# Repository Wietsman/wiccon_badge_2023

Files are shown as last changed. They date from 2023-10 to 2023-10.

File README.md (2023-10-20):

# Wiccon Badge 2023

# What is this repo: 
  This repo contains the source + firmware + PCB design for the WICCON 2023 Badge (https://wiccon.nl/) (not the SAO)

  Badge front:
Frontside  

  Badge back:
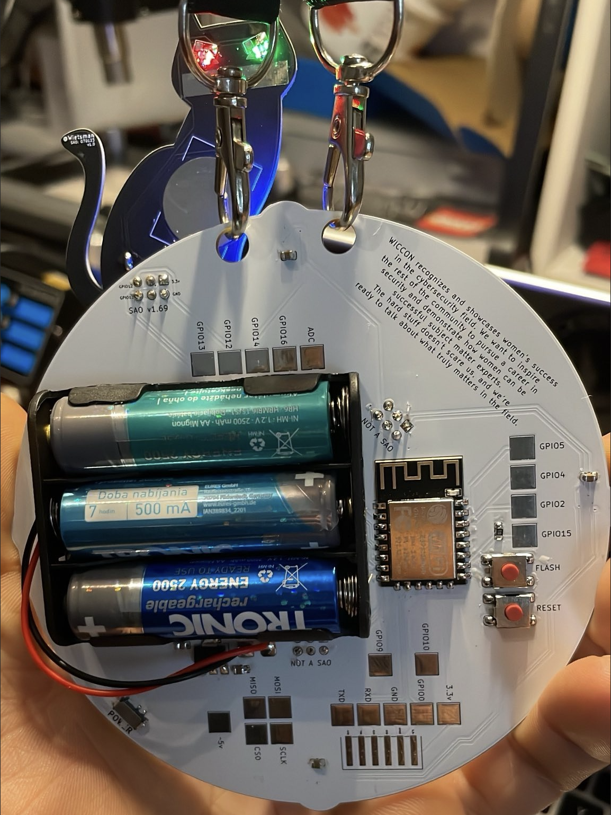
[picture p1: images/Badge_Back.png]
Backside
    

  The Folder PCB contains the main badge and the addon, created with KiCad.
  # Main badge
  ## Frontside
  * 4 WS2812B on the front. (made a mistake they are adressed counter clockwise)
  * 1 MODE button on the front to switch LED effects
  * 2 6 pin female connecter to attach the addon board (Cat and moon)
  * 1 SAO v1.69 (Shitty Addon) (https://hackaday.com/2019/03/20/introducing-the-shitty-add-on-v1-69bis-standard/)
  * |  PIN  |      Description      |
    |-------|-----------------------|
    | 3.3v  | Positive power supply |
    | GND   | Ground                |
    | SCL   | Not connected (sorry) |
    | SDA   | Not connected (sorry) |        
    | GPI12 | General-purpose pin   |
    | GPI13 | General-purpose pin   |    
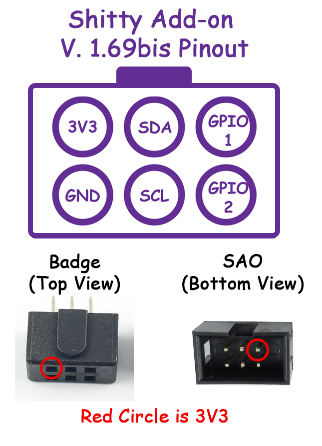
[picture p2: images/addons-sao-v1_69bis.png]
SAO v1.69


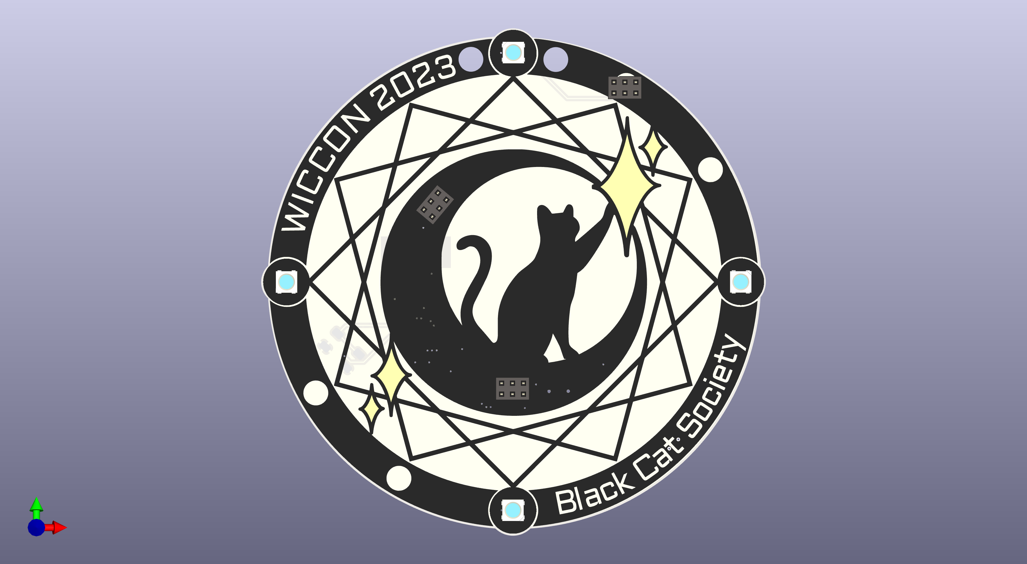
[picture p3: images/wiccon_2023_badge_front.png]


## Backside
* ESP8622
* Powerswitch
* Reset button
* Flash button
* Batterybox
* stepdown converter (3.6-4.5v) to 3.3v
* couple of capacitor for WS2812B and stepdown converter
* 1 resistor
* lots of test pads so you can reuse the badge for other projects

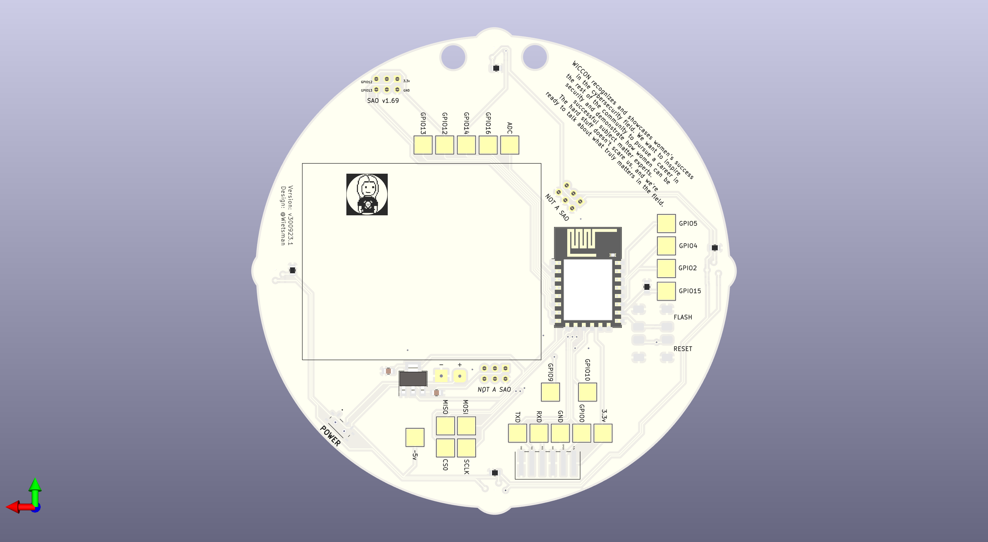
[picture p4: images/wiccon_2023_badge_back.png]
back3d


## Schematic
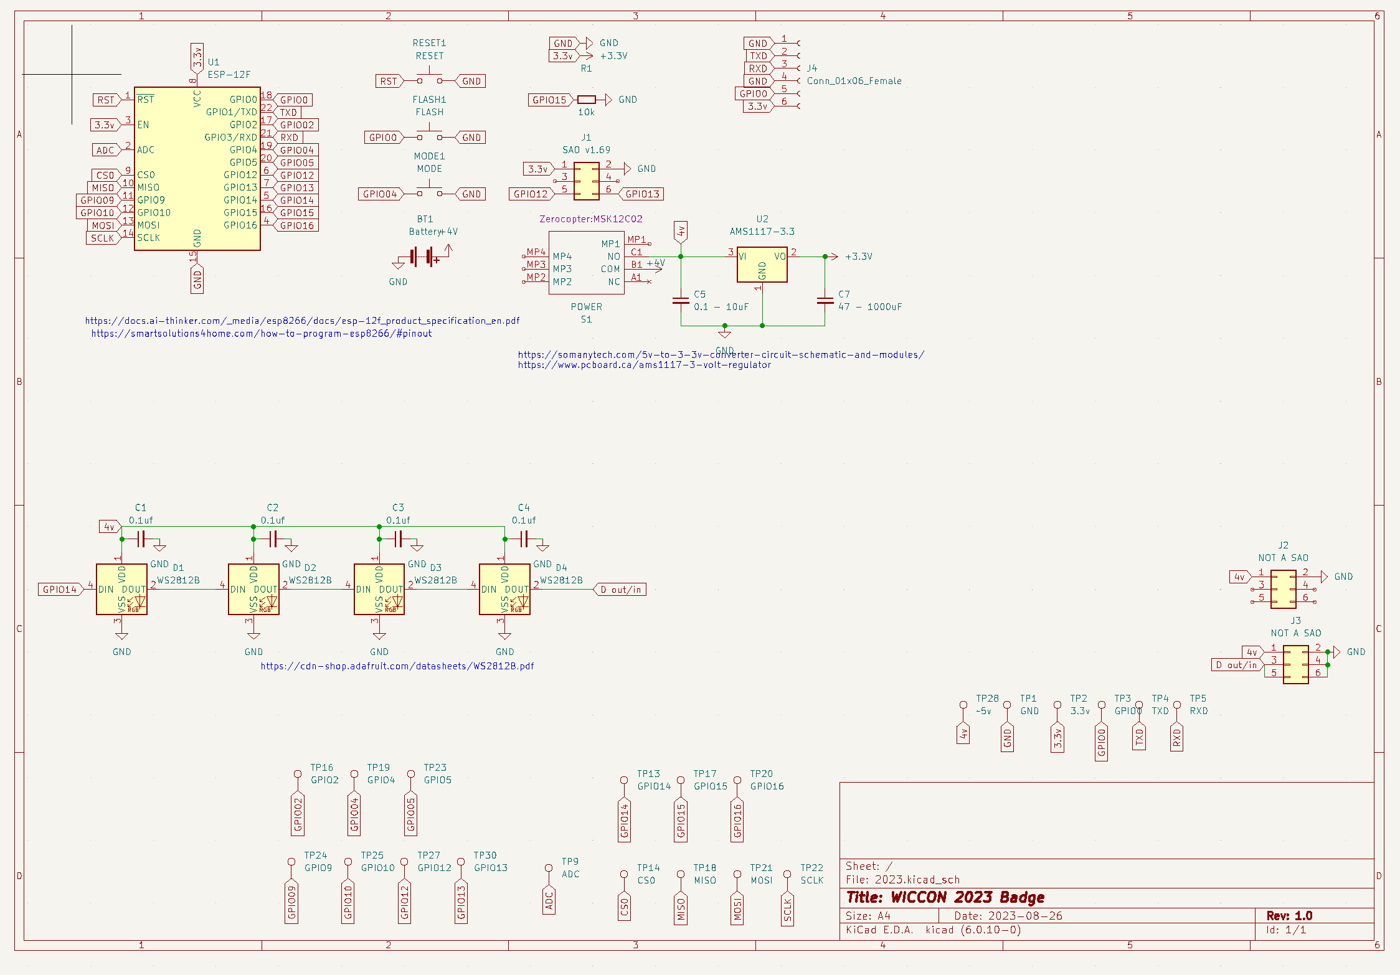
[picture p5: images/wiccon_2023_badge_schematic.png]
Schematic


## Usage
The badge has been designed to be reused for your project. The test pads can be used to solder anything to it and you can flash the ESP. 

You can use all the pads/pins except for (because i orderd the wrong ESP.....):
* MISO
* MOSI
* GPIO09
* GPIO10
* SCLK
* CSO

The following pins need are "special":
* GPIO00 pull to ground on boot to flash the ESP (or press flash button)
* GPIO15 is pulled to ground through a 10k resistor otherwise the ESP wont boot.

Flashing your own firmware, connect UART to tx/rx gnd power the device by battery or external 3.3v power. Hold the flash button, then press reset, release the flash button. Now you can flash your own firmware with esptool.py, arduino ide or what ever you want.

# Addon board
There are 2 addon boards for WICCON 2023, for guests (black cat and moon) and orga (purple moon, silver cat)
## Guestboard
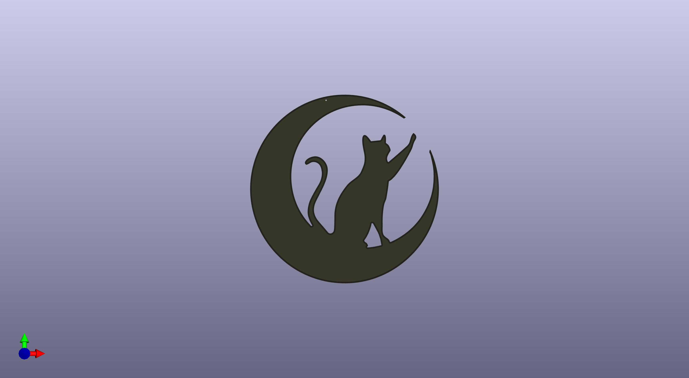
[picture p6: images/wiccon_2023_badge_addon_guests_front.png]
guest cat

## Orgaboard
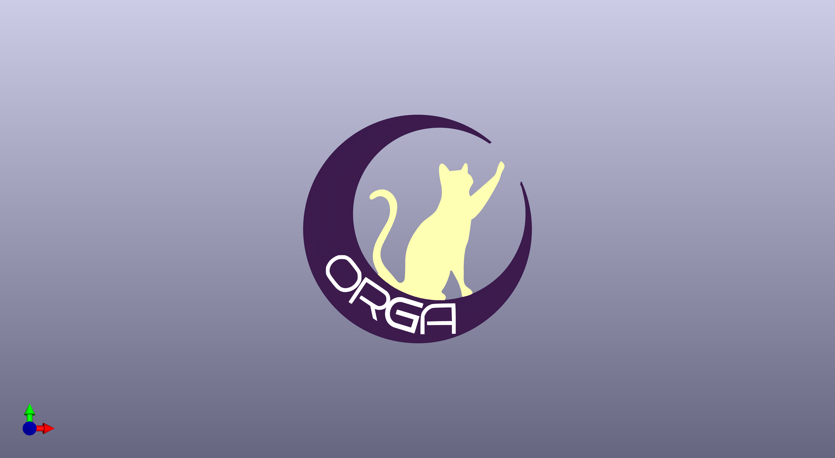
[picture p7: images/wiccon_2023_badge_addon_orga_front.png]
orga cat

## Schematic
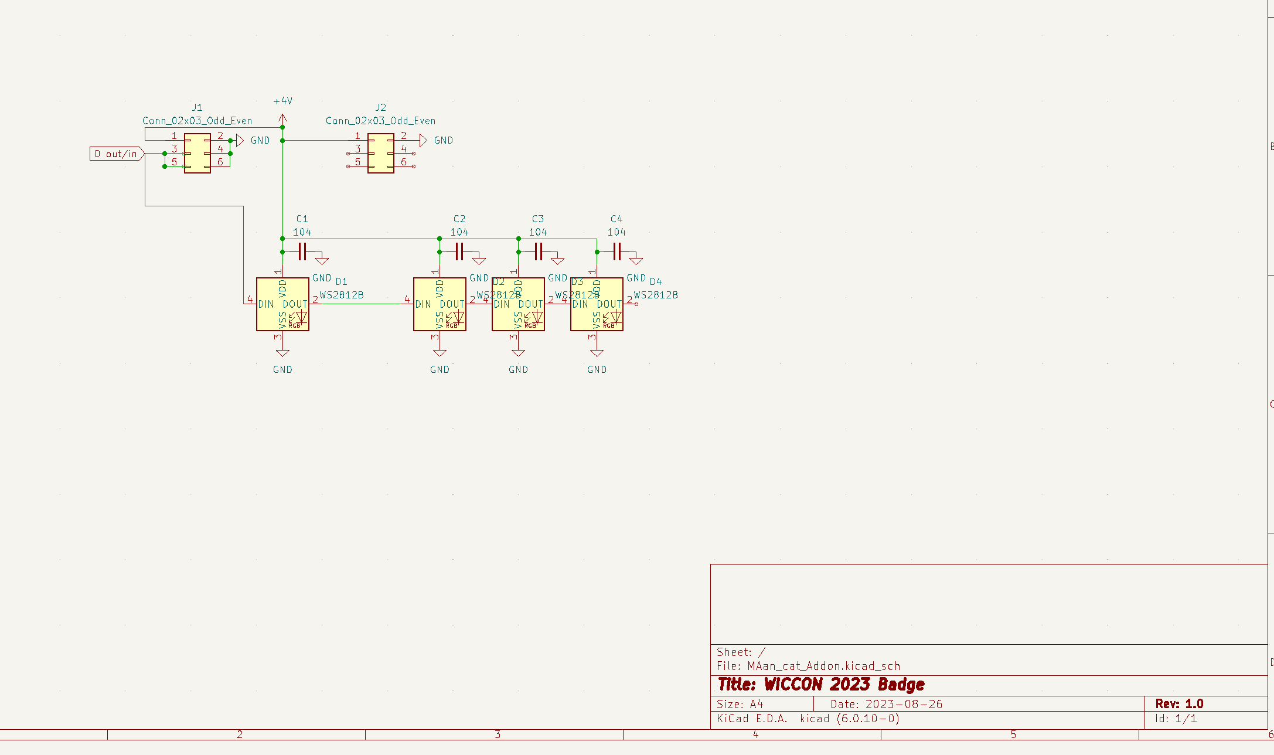
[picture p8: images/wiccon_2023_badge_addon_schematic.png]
schematic


## Backside
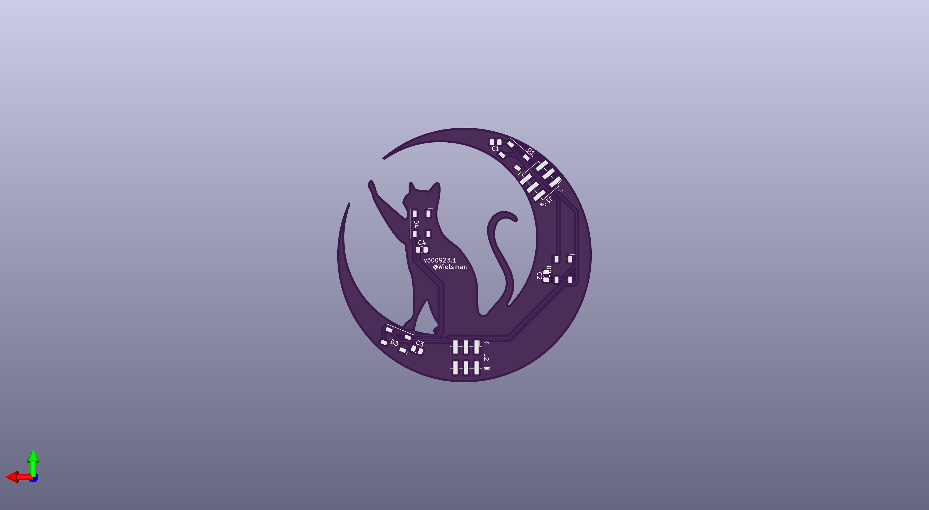
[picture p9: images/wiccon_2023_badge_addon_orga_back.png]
backside


# Questions, remarks or whatever!

If you have any questions please drop me a message: 
* twitter: [twitter](https://twitter.com/wietsman)
* Website: [WBSEC.nl](https://www.wbsec.nl)

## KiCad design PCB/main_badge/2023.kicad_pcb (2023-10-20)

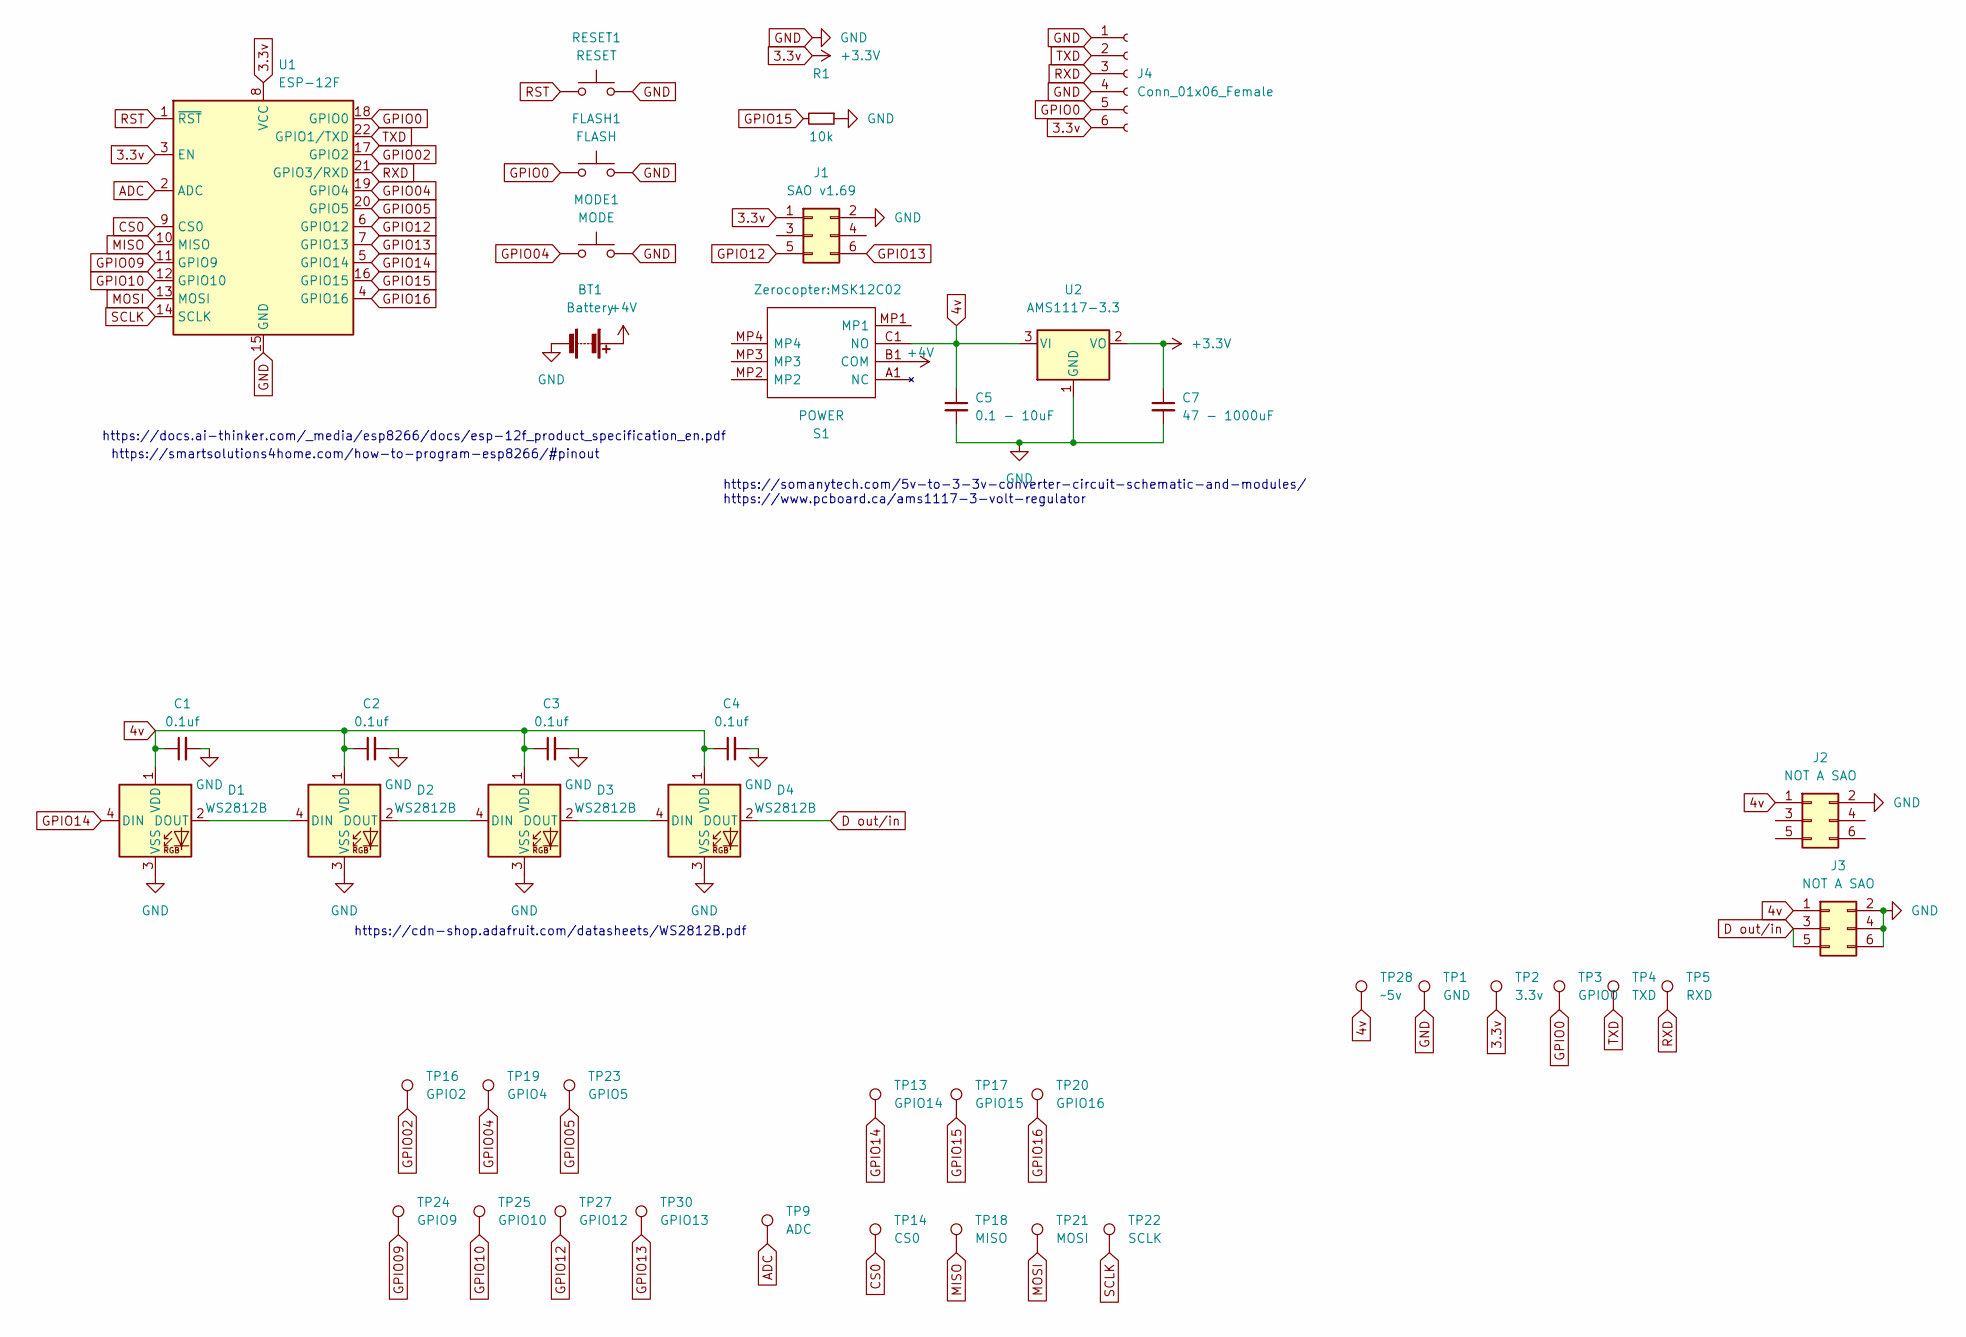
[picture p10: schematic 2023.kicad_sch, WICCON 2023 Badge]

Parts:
BT1: Battery; Battery_holder_3AA
C1, C2, C3, C4: 0.1uf; R_0805_2012Metric
C5: 0.1 - 10uF; C_0805_2012Metric_Pad1.18x1.45mm_HandSolder
C7: 47 - 1000uF; C_0805_2012Metric_Pad1.18x1.45mm_HandSolder
D1, D2, D3, D4: WS2812B; LED_WS2812B_PLCC4_5.0x5.0mm_P3.2mm
FLASH1: FLASH; sw_tactile_4x4
J1: SAO v1.69; PinSocket_2x03_P2.54mm_Vertical
J2, J3: NOT A SAO; PinSocket_2x03_P2.54mm_Vertical
J4: Conn_01x06_Female; Harting_har-flexicon_14110413010xxx_1x04-MP_P2.54mm_Horizon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
MODE1: MODE; sw_tactile_4x4
R1: 10k; R_0805_2012Metric_Pad1.20x1.40mm_HandSolder
RESET1: RESET; sw_tactile_4x4
S1: POWER; MSK12C02; Manufacturer_Part_Number MSK12C02
TP1: GND; TestPoint_Pad_4.0x4.0mm
TP2: 3.3v; TestPoint_Pad_4.0x4.0mm
TP3: GPIO0; TestPoint_Pad_4.0x4.0mm
TP4: TXD; TestPoint_Pad_4.0x4.0mm
TP5: RXD; TestPoint_Pad_4.0x4.0mm
TP9: ADC; TestPoint_Pad_4.0x4.0mm
TP13: GPIO14; TestPoint_Pad_4.0x4.0mm
TP14: CS0; TestPoint_Pad_4.0x4.0mm
TP16: GPIO2; TestPoint_Pad_4.0x4.0mm
TP17: GPIO15; TestPoint_Pad_4.0x4.0mm
TP18: MISO; TestPoint_Pad_4.0x4.0mm
TP19: GPIO4; TestPoint_Pad_4.0x4.0mm
TP20: GPIO16; TestPoint_Pad_4.0x4.0mm
TP21: MOSI; TestPoint_Pad_4.0x4.0mm
TP22: SCLK; TestPoint_Pad_4.0x4.0mm
TP23: GPIO5; TestPoint_Pad_4.0x4.0mm
TP24: GPIO9; TestPoint_Pad_4.0x4.0mm
TP25: GPIO10; TestPoint_Pad_4.0x4.0mm
TP27: GPIO12; TestPoint_Pad_4.0x4.0mm
TP28: ~5v; TestPoint_Pad_4.0x4.0mm
TP30: GPIO13; TestPoint_Pad_4.0x4.0mm
U1: ESP-12F; ESP-12E
U2: AMS1117-3.3; SOT-223-3_TabPin2

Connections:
3.3v: C7.1, J1.1, J4.6, TP2.1, U1.3 (EN), U1.8 (VCC), U2.2 (VO)
4v: C1.1, C2.1, C3.1, C4.1, C5.1, D1.1 (VDD), D2.1 (VDD), D3.1 (VDD), D4.1 (VDD), J2.1, J3.1, S1.C1 (NO), TP28.1, U2.3 (VI)
+4V: BT1.1 (+), S1.B1 (COM)
ADC: TP9.1, U1.2 (ADC)
CS0: TP14.1, U1.9 (CS0)
D out/in: D4.2 (DOUT), J3.3, J3.5
GND: BT1.2 (-), C1.2, C2.2, C3.2, C4.2, C5.2, C7.2, D1.3 (VSS), D2.3 (VSS), D3.3 (VSS), D4.3 (VSS), FLASH1.2, J1.2, J2.2, J3.2, J3.4, J3.6, J4.1, J4.4, MODE1.2, R1.1, RESET1.2, TP1.1, U1.15 (GND), U2.1 (GND)
GPIO0: FLASH1.1, J4.5, TP3.1, U1.18 (GPIO0)
GPIO02: TP16.1, U1.17 (GPIO2)
GPIO04: MODE1.1, TP19.1, U1.19 (GPIO4)
GPIO05: TP23.1, U1.20 (GPIO5)
GPIO09: TP24.1, U1.11 (GPIO9)
GPIO10: TP25.1, U1.12 (GPIO10)
GPIO12: J1.5, TP27.1, U1.6 (GPIO12)
GPIO13: J1.6, TP30.1, U1.7 (GPIO13)
GPIO14: D1.4 (DIN), TP13.1, U1.5 (GPIO14)
GPIO15: R1.2, TP17.1, U1.16 (GPIO15)
GPIO16: TP20.1, U1.4 (GPIO16)
MISO: TP18.1, U1.10 (MISO)
MOSI: TP21.1, U1.13 (MOSI)
unnamed: D1.2 (DOUT), D2.4 (DIN)
unnamed: D2.2 (DOUT), D3.4 (DIN)
unnamed: D3.2 (DOUT), D4.4 (DIN)
RST: RESET1.1, U1.1 (~RST)
RXD: J4.3, TP5.1, U1.21 (GPIO3/RXD)
SCLK: TP22.1, U1.14 (SCLK)
TXD: J4.2, TP4.1, U1.22 (GPIO1/TXD)

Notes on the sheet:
https://somanytech.com/5v-to-3-3v-converter-circuit-schematic-and-modules/ https://www.pcboard.ca/ams1117-3-volt-regulator
https://docs.ai-thinker.com/_media/esp8266/docs/esp-12f_product_specification_en.pdf
https://smartsolutions4home.com/how-to-program-esp8266/#pinout
https://cdn-shop.adafruit.com/datasheets/WS2812B.pdf

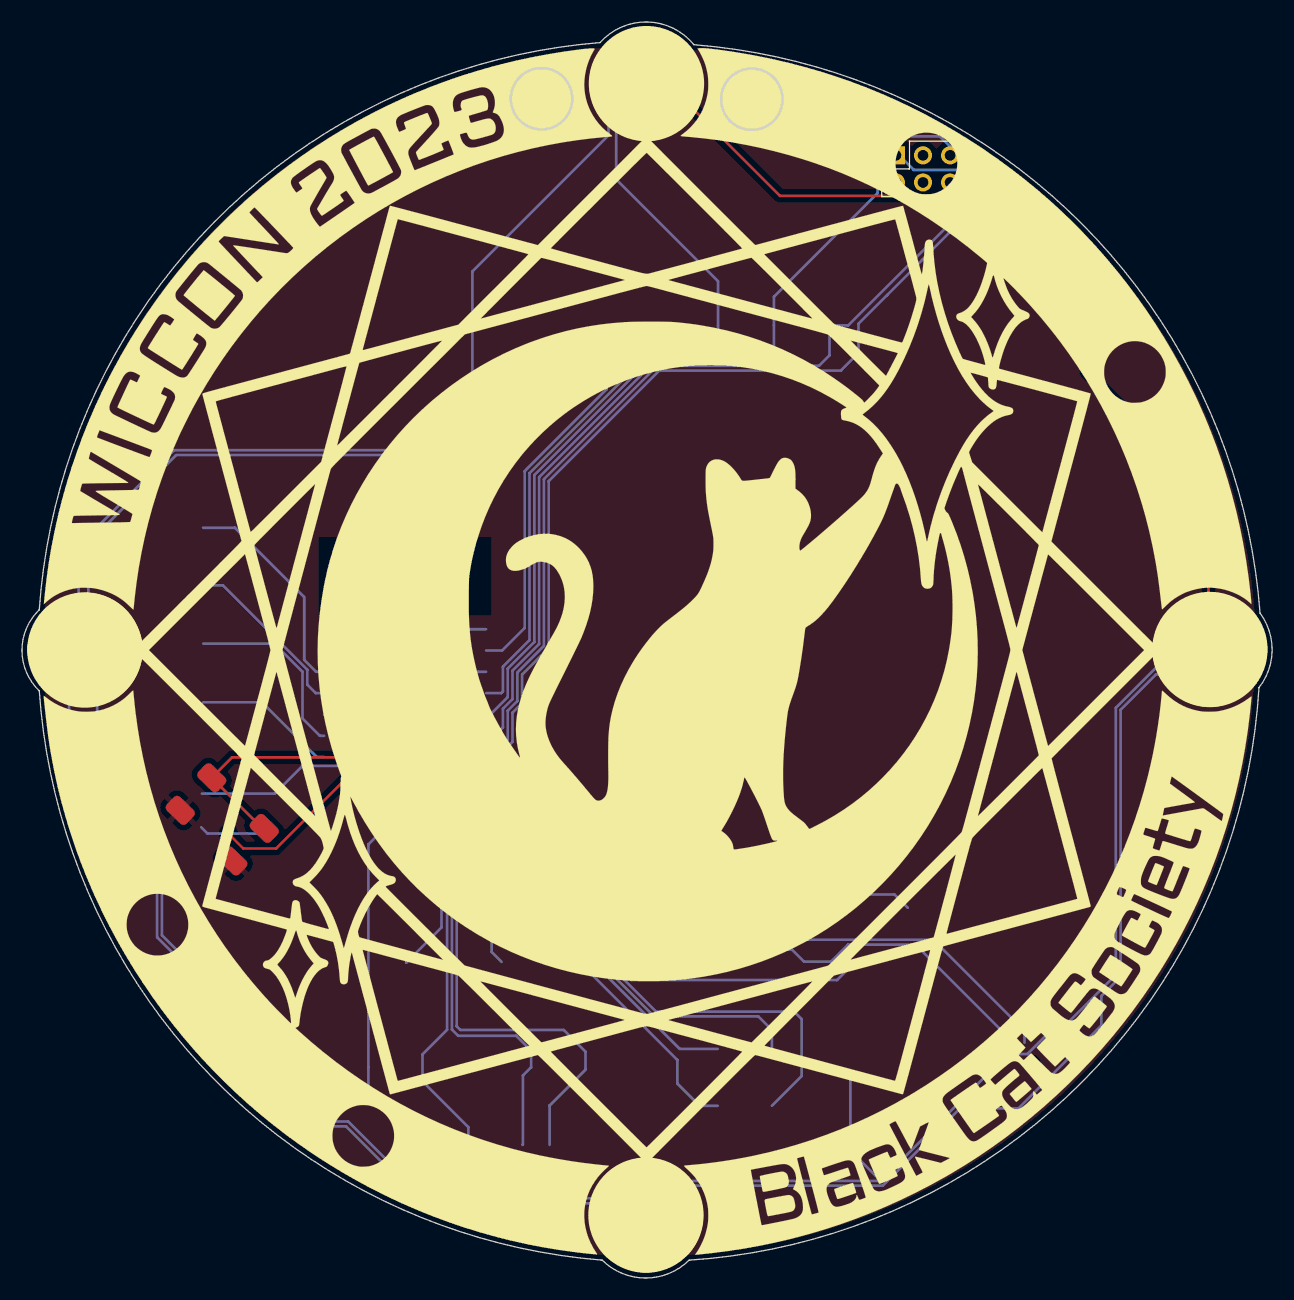
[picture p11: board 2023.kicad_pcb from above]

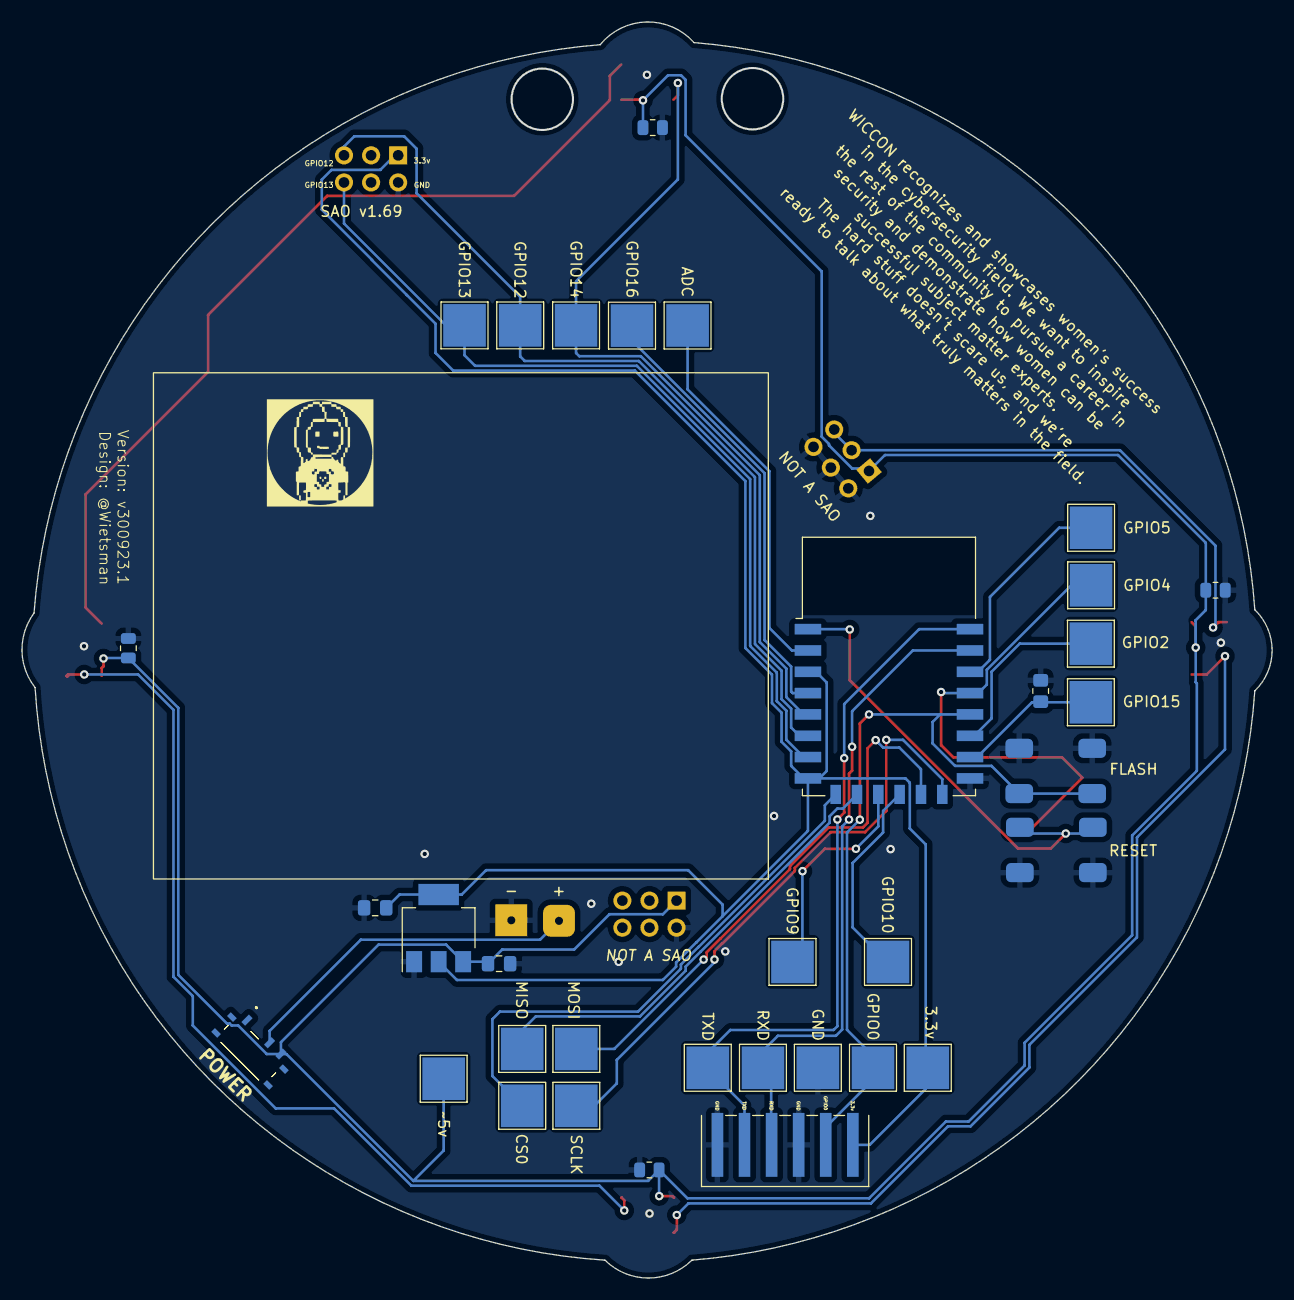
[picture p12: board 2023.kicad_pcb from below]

Board: 2 copper layers, 117.3 x 117.8 mm, 44 parts (35 on the bottom side), 27 nets.

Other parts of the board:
Ref**: Val**; WICCON_CAT_MOON_STAR2

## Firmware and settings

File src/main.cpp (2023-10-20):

#include <Adafruit_NeoPixel.h>
#include <painlessMesh.h>

#define MESH_PREFIX "WICCON_2023"
#define MESH_PASSWORD "WICCON_2023_IS_FUN!!!!"
#define MESH_PORT 5555

#define NEOPIXEL_PIN 14        // Pin where the NeoPixel is connected
#define NUMPIXELS 8         // Number of NeoPixels
Adafruit_NeoPixel strip = Adafruit_NeoPixel(NUMPIXELS, NEOPIXEL_PIN, NEO_GRB + NEO_KHZ800);

const int buttonPin = 4;  // Pin number for the button
int buttonState = HIGH;   // Variable to store the button state
int lastButtonState = HIGH; // Variable to store the previous button state
bool isRunning = true;    // Flag to control the effect
int effectNumber = 0;

unsigned long previousMillis = 0;
unsigned long pm = 0;
const long interval = 1000; // Interval between effect changes in milliseconds

bool resumePause();

void continuousEffect();
void theaterChase(uint32_t color, int wait);
void rainbowCycle(int wait);
void policeLights(int wait);
void sparkle(int wait);
void colorWipe(uint32_t color, int wait);
void cylonScanner(uint32_t color, int eyeSize, int speed);
void colorFade(uint32_t color1, uint32_t color2, int steps, int wait);
void comet(uint32_t color, int tailLength, int wait);
uint32_t Wheel(byte WheelPos);


// Morse Code Definitions
#define DOT_DURATION 250 // Duration of a dot in milliseconds
#define DASH_DURATION 3 * DOT_DURATION // Duration of a dash (3 times dot duration)
#define SYMBOL_GAP 3 * DOT_DURATION // Gap between symbols (3 times dot duration)
#define WORD_GAP 7 * DOT_DURATION // Gap between words (7 times dot duration)

void sendMorseCode(const char *message);


painlessMesh mesh;
String receivedMessage = "";
bool isMasterMesh = false;
bool masterIsClose = false;
uint32_t masterID;
void receivedCallback(uint32_t from, String &msg) {
  masterID = from; 
  // Serial.printf("Received from %u: %s\n", from, msg.c_str());
  receivedMessage = msg;  // Store the received message in the global variable
}

void setup() {
  strip.begin();
  strip.show();  // Initialize all NeoPixels to 'off'
  pinMode(buttonPin, INPUT_PULLUP); // Configure the button pin as an input with a pull-up resistor
  // mesh.setDebugMsgTypes(ERROR | STARTUP | CONNECTION);  // Enable debug messages
  // mesh.setDebugMsgTypes(CONNECTION);
  mesh.setContainsRoot(true);
  mesh.init(MESH_PREFIX, MESH_PASSWORD, MESH_PORT);
  mesh.onReceive(receivedCallback);  // Register the receivedCallback

  Serial.begin(9600);
}

void loop() {
  unsigned long currentMillis = millis();
  resumePause();

  if (isRunning) {

    // Run the NeoPixel effect when the effect is not paused
    if (currentMillis - previousMillis >= interval) {
      previousMillis = currentMillis;

      // Clear the NeoPixel strip
      strip.fill(0); // Turn off NeoPixels
      strip.show();
      strip.clear();

      // Call your continuous effect function here
      continuousEffect();
    }
  } else {

    // When the effect is paused, you can keep the NeoPixels off or set them to a specific state
    strip.fill(0); // Turn off NeoPixels
    strip.show();
    strip.clear();
  }

  strip.show();
  masterIsClose = false;
  // Your non-blocking code for other tasks can go here


}

// Define your continuous NeoPixel effect function
void continuousEffect() {
  // Your code to create the continuous NeoPixel effect goes here
  // For example, you can implement a color cycle or any other animation
  switch(effectNumber){
    case 0:
      strip.fill(0); // Turn off NeoPixels
      strip.show();
      sendMorseCode("To find the truth  shoot for the moon  ");

      break;
    case 1:
      theaterChase(strip.Color(random(256), random(256), random(256)), 250);
      break;
    case 2:
      rainbowCycle(50);
      break;
    case 3:
      policeLights(50);
      break;
    case 4:
      sparkle(100);
      break;
    case 5:
      colorWipe(strip.Color(random(256), random(256), random(256)), 50);
      break;
    case 6:
      cylonScanner(strip.Color(random(256), random(256), random(256)), 3, 100);
      break;
    case 7:
      colorFade(strip.Color(random(256), random(256), random(256)), strip.Color(random(256), random(256), random(256)), 100, 30);
      break;
    case 8:
      comet(strip.Color(random(256), random(256), random(256)), 3, 100); // Comet with red tail
      break;
  }
}


// NeoPixel effect functions

void rainbowCycle(int wait) {
  for (int j = 0; j < 256; j++) { // One cycle of color wheel
    for (int i = 0; i < strip.numPixels(); i++) {
      if (i <= 3) {
        strip.setPixelColor(i, Wheel(((i * 256 / strip.numPixels()) + j) & 255));
      } else {
        strip.setPixelColor(i, Wheel(((i * 256 / strip.numPixels()) + j) & 255));
      }
      if (!resumePause()){ 
        return; 
      }
    }
    if (!resumePause()){ 
      return; 
    }

    strip.show();
    delay(wait);
  }
  return;
}

void colorWipe(uint32_t color, int wait) {
  for (int i = 0; i < strip.numPixels(); i++) {
    if (!resumePause()){ 
      return; 
    }
    if (i <= 3) {
      strip.setPixelColor(i, color/4);
    } else {
      strip.setPixelColor(i, color);
    }
    strip.show();
    delay(wait);
  }
}

bool resumePause(){
  mesh.update();
    // Serial.println(mesh.getAPIP());
    // Serial.println(mesh.getNodeId());
    // Serial.println(mesh.getStationIP());

    // Serial.println("WiFi signal: " + String(WiFi.RSSI()) + " db");
  if (!isMasterMesh) {
    if (!receivedMessage.isEmpty()) {
      if (receivedMessage == "I_AM_THE_MASTER!" && !masterIsClose){
        masterIsClose = true;
      // Serial.println("Processing received message: " + receivedMessage);
        Serial.println("Master is close, start listening");
      
        while (mesh.isConnected(masterID)){
          Serial.println(mesh.isConnected(masterID));
          policeLights(50);
        }
      }

      receivedMessage = "";
    }
  } else {
    mesh.sendBroadcast("I_AM_THE_MASTER!");
  }
  unsigned long cm = millis();
  if (cm - pm >= interval/2) {
      pm = cm;
    Serial.println(String(effectNumber));
    buttonState = digitalRead(buttonPin);
    if (buttonState != lastButtonState) {
      if (buttonState == LOW) {
        // isRunning = !isRunning; // Toggle the running state when the button is pressed
        // Serial.println(isRunning ? "Effect resumed" : "Effect paused");
      // } else {
        effectNumber = effectNumber + 1;
        if (effectNumber == 9){
          effectNumber = 0;
        }
        return false;
      }
      lastButtonState = buttonState;
    }
  }
  
  return true;

}

void theaterChase(uint32_t color, int wait) {
  for (int a = 0; a < 10; a++) { // Repeat 10 times
    if (!resumePause()){ 
      return; 
    }
    for (int b = 0; b < 3; b++) {
      strip.clear();
      if (!resumePause()){ 
        return; 
      }
      for (int c = b; c < strip.numPixels(); c += 3) {
        strip.setPixelColor(c, color);
        if (!resumePause()){ 
          return; 
        }
      }
      strip.show();
      delay(wait);
    }
  }
}

void policeLights(int wait) {
  for (int i = 0; i < 5; i++) { // Repeat 5 times
    if (!resumePause()){ 
      return; 
    }
    strip.setPixelColor(0, strip.Color(112, 0, 0)); // Red
    strip.setPixelColor(1, strip.Color(112, 0, 0)); // Red
    strip.setPixelColor(2, strip.Color(112, 0, 0)); // Red
    strip.setPixelColor(3, strip.Color(112, 0, 0)); // Red
    strip.setPixelColor(4, strip.Color(0, 0, 255)); // Blue
    strip.setPixelColor(5, strip.Color(0, 0, 255)); // Blue
    strip.setPixelColor(6, strip.Color(0, 0, 255)); // Blue
    strip.setPixelColor(7, strip.Color(0, 0, 255)); // Blue
    strip.show();
    if (!resumePause()){ 
      return; 
    }
    delay(wait);
    if (!resumePause()){ 
      return; 
    }
    strip.clear();
    strip.show();
    delay(wait);
  }
}

void sparkle(int wait) {
  for (int i = 0; i < strip.numPixels(); i++) {
    if (!resumePause()){ 
      return; 
    }
    if (i < 3){ 
      strip.setPixelColor(i, strip.Color(random(125), random(125), random(125)));
    } else {
      strip.setPixelColor(i, strip.Color(random(256), random(256), random(256)));
    }
    strip.show();
    delay(wait);
    if (!resumePause()){ 
      return; 
    }
    strip.setPixelColor(i, 0); // Turn off the pixel
  }
  if (!resumePause()){ 
    return; 
  }

  strip.show();
}

// Wheel function for rainbow effect
uint32_t Wheel(byte WheelPos) {
  if (WheelPos < 85) {
    return strip.Color(WheelPos * 3, 255 - WheelPos * 3, 0);
  } else if (WheelPos < 170) {
    WheelPos -= 85;
    return strip.Color(255 - WheelPos * 3, 0, WheelPos * 3);
  } else {
    WheelPos -= 170;
    return strip.Color(0, WheelPos * 3, 255 - WheelPos * 3);
  }
}

// Cylon Scanner
void cylonScanner(uint32_t color, int eyeSize, int speed) {
  
  for (int i = 0; i < strip.numPixels() - eyeSize + 1; i++) {
    if (!resumePause()){ 
      return; 
    }
    strip.clear();
    for (int j = 0; j < eyeSize; j++) {
      if (!resumePause()){ 
        return; 
      }
      strip.setPixelColor(i + j, color);
    }
    strip.show();
    delay(speed);
  }
  if (!resumePause()){ 
    return; 
  }
  for (int i = strip.numPixels() - eyeSize + 1; i > 0; i--) {
    if (!resumePause()){ 
      return; 
    }
    strip.clear();
    for (int j = 0; j < eyeSize; j++) {
      strip.setPixelColor(i + j - 1, color);
      if (!resumePause()){ 
        return; 
      }
    }
    strip.show();
    delay(speed);
  }
}

//Color Fade
void colorFade(uint32_t color1, uint32_t color2, int steps, int wait) {
  uint8_t r1 = (color1 >> 16) & 0xFF;
  uint8_t g1 = (color1 >> 8) & 0xFF;
  uint8_t b1 = color1 & 0xFF;
  uint8_t r2 = (color2 >> 16) & 0xFF;
  uint8_t g2 = (color2 >> 8) & 0xFF;
  uint8_t b2 = color2 & 0xFF;

  for (int k = 0; k < steps; k++) {
    uint8_t r = map(k, 0, steps - 1, r1, r2);
    uint8_t g = map(k, 0, steps - 1, g1, g2);
    uint8_t b = map(k, 0, steps - 1, b1, b2);
    uint32_t blendedColor = strip.Color(r, g, b);

    strip.fill(blendedColor);
    strip.show();
    delay(wait);
  }
}


//Comet
void comet(uint32_t color, int tailLength, int wait) {
  for (int i = 0; i < strip.numPixels() + tailLength; i++) {
    if (!resumePause()){ 
      return; 
    }
    // Calculate the position of the comet
    int pos = i - tailLength;
    
    // Draw the comet
    for (int j = 0; j < strip.numPixels(); j++) {
      if (!resumePause()){ 
        return; 
      }
      if (j >= pos && j < pos + tailLength) {
        strip.setPixelColor(j, color);
        if (!resumePause()){ 
           return; 
        }
      } else {
        strip.setPixelColor(j, 0);
        if (!resumePause()){ 
          return; 
        }
      }
    }
    
    strip.show();
    delay(wait);
  }
}

void sendMorseCode(const char *message) {
  const char *morseCode[] = {
    ".-", "-...", "-.-.", "-..", ".", "..-.", "--.", "....", "..", ".---",
    "-.-", ".-..", "--", "-.", "---", ".--.", "--.-", ".-.", "...", "-",
    "..-", "...-", ".--", "-..-", "-.--", "--..", " ", // Morse code for letters and space
  };
  
  for (int i = 0; message[i] != '\0'; i++) {
    if (!resumePause()){ 
      return; 
    }
    char c = tolower(message[i]);
    if (c >= 'a' && c <= 'z') {
      if (!resumePause()){ 
        return; 
      }
      int index = c - 'a';
      for (int j = 0; morseCode[index][j] != '\0'; j++) {
        if (!resumePause()){ 
          return; 
        }
        char symbol = morseCode[index][j];
        switch (symbol) {
          case '.':
            strip.fill(strip.Color(random(256), random(256), random(256))); // Turn NeoPixels red for a dot
            strip.show();
            delay(DOT_DURATION);
            break;
          case '-':
            strip.fill(strip.Color(random(256), random(256), random(256))); // Turn NeoPixels blue for a dash
            strip.show();
            delay(DASH_DURATION);
            break;
        }
        strip.fill(0); // Turn off NeoPixels for the gap
        strip.show();
        delay(SYMBOL_GAP);
      }
    } else if (c == ' ') {
      if (!resumePause()){ 
        return; 
      }
      strip.fill(0); // Space between words
      strip.show();
      delay(WORD_GAP);
    }
  }
  if (!resumePause()){ 
    return; 
  }
}
